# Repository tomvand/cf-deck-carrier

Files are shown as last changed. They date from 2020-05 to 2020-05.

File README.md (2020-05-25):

# Crazyflie 2 deck carrier
[](https://creativecommons.org/licenses/by/4.0/)

Rev 0.1A

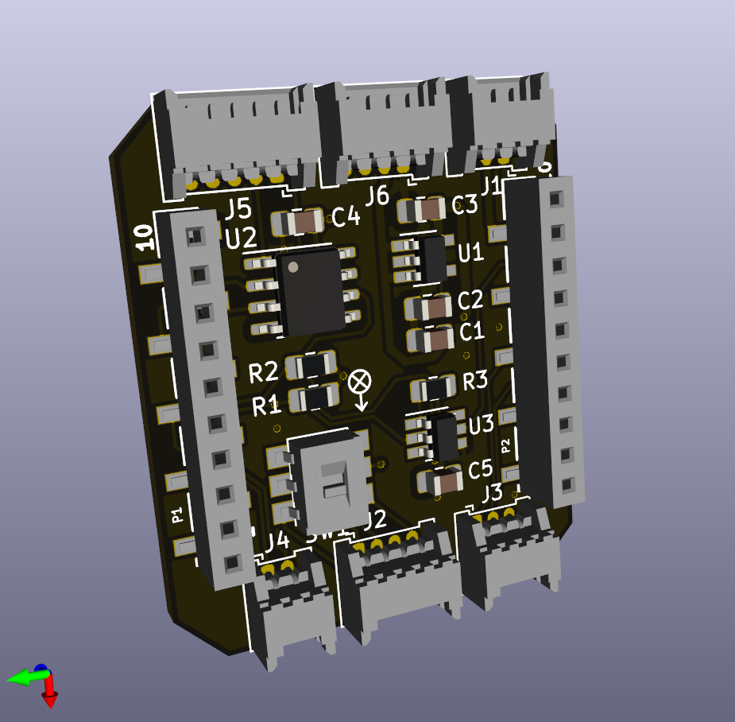
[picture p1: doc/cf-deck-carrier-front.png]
Front


Schematic: [here](cf-deck-carrier.pdf)

Gerbers: [here](gerber/cf-deck-carrier/)

License: [CC BY 4.0](https://creativecommons.org/licenses/by/4.0/). \
Additionally, if you use this design for scientific work, please add a footnote or reference to this webpage: \
Tom van Dijk (2020). *Crazyflie 2 deck carrier*. Micro Air Vehicle Lab (MAVLab), TU Delft. Retrieved from https://github.com/tomvand/cf-deck-carrier

This carrier board lets the Crazyflie 2 decks by [Bitcraze AB ](https://www.bitcraze.io/) be carried by other drones. The board functions similarly to a breakout board but with additional functions. The board is originally designed for the Eachine Trashcan, but may also be useful for other drones.

Nearly all of the features on this carrier board are optional, unused components can be left out to save weight and assembly time. Refer to the *optional features* section below to check which components should be installed for your application.

## Interface
The carrier board should be connected to an autopilot using the connectors `J1` to `J5`. The connectors are grouped by function. In nearly all cases the board can be connected directly to the corresponding autopilot pins.

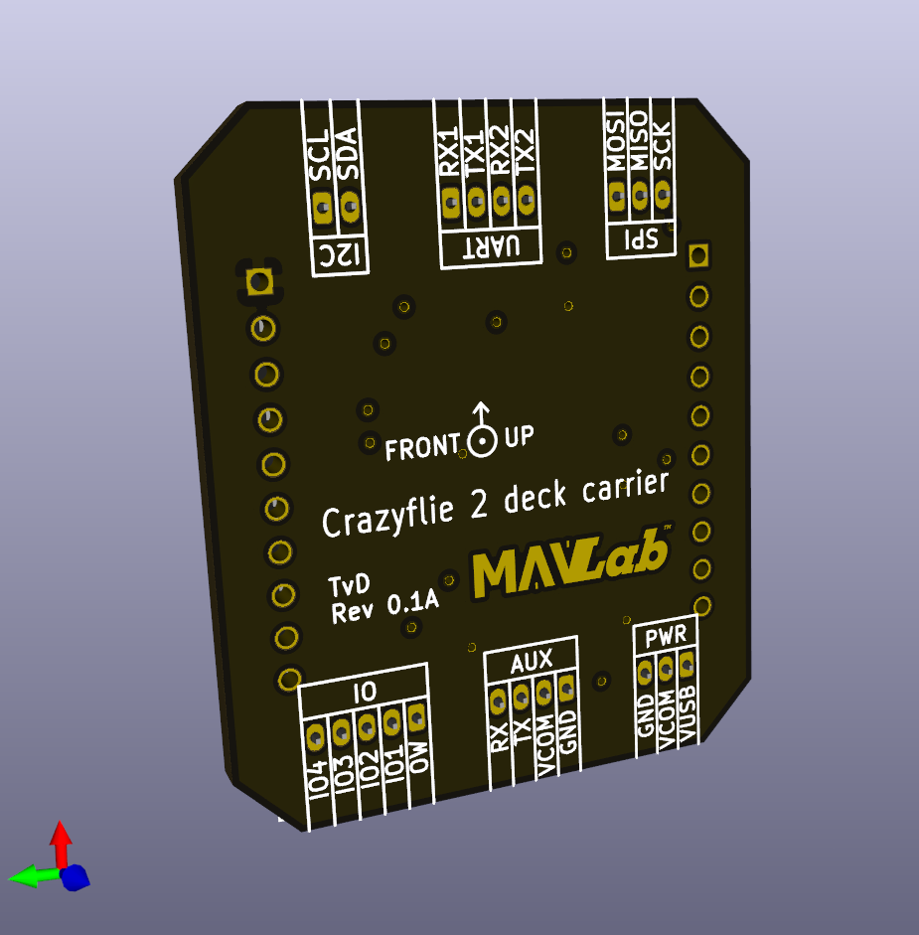
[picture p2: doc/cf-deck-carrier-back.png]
Pinouts


PWR (`J1`):
- VCOM provides power to this board and the decks. VCOM does not need to be regulated.
- VUSB is a power supply *to* the drone, for instance using the Qi charging deck.

UART (`J2`):

SPI (`J3`):
- The IO pins on `J5` are typically used as Chip Select.

I2C (`J4`):

IO (`J5`):
- IO functionality can be replaced by the on-board I2C-to-GPIO and I2C-to-1-Wire bridges for controllers with few free pins.

AUX (`J6`):
- The auxiliary UART is connected directly to either UART1 or UART2.

## Bill of materials
| Ref | Qnty | Value | Cmp name | Footprint | Approx. total cost / 5 |
|---|---|---|---|---|---|
| PCB, | 1 | | | | € 4.57 |
| | | | | |------------------------|
| Subtotal | | | | | € 4.57 |
| | | | | |------------------------|
| C1, | 1 | 1uF | C | 0805 | € 0.20 |
| C2, | 1 | 10nF | C | 0805 | € 0.20 |
| C3, | 1 | 4.7uF | C | 0805 | € 0.20 |
| C4, C5, | 2 | 0.1uF | C | 0805 | € 0.40 |
| R1, R2, R3,  | 3 | 2.2k | R | 0805 | € 1.20 |
| | | | | |------------------------|
| Subtotal | | | | | € 2.20 |
| | | | | |------------------------|
| U1, | 1 | LP2985-3.0 | LP2985-3.0 | SOT-23-5  | € 3.70 |
| U2, | 1 | PCA9536D | PCA9536D | SOIC-8 | € 7.15 |
| U3, | 1 | DS2484 | DS2484 | SOT-23-6  | € 3.35 |
| | | | | |------------------------|
| Subtotal | | | | | € 14.20 |
| | | | | |------------------------|
| J1, | 1 | PWR | Molex PicoBlade 1x3 Horizontal Through-hole 53048-0310 | | € 1.55 |
| J2, | 1 | UART | Molex PicoBlade 1x4 Horizontal Through-hole 53048-0410 | | € 1.85 |
| J3, | 1 | SPI | Molex PicoBlade 1x3 Horizontal Through-hole 53048-0310 | | € 1.55 |
| J4, | 1 | I2C | Molex PicoBlade 1x2 Horizontal Through-hole 53048-0210 | | € 1.25 |
| J5, | 1 | IO | Molex PicoBlade 1x5 Horizontal Through-hole 53048-0510 | | € 1.90 |
| J6, | 1 | UART_AUX | Molex PicoBlade 1x4 Horizontal Through-hole 53048-0410 | | € 1.85 |
| P1, | 1 | CF_EXP_LEFT  | BF090-10-X-B2 | | € 6.60 |
| P2, | 1 | CF_EXP_RIGHT | BF090-10-X-B2 | | € 6.60 |
| SW1, | 1 | CAS-220 | CAS-220B1 | | € 9.20 |
| | | | | |------------------------|
| Subtotal | | | | | € 32.35 |
| | | | | |------------------------|
| Total | | | | | € 53.32 / 5 |

## Ordering information
### PCB
- PCB size: 33x28mm
- PCB layers: 4
- Silkscreen: both sides
- Min. Trace/Space: 6 mil
- Min. Drill: 15 mil

Find the gerber files [here](gerber/cf-deck-carrier/).

PCB manufactoring cost: ~€4.57 / 5 (excl. shipping cost, at [JLCPCB](https://jlcpcb.com/), estimated by [pcbshopper](https://pcbshopper.com/) on Wednesday May 20th 2020)

### PCB with partial assembly
SMT assembly files for JLCPCB: [here](gerber/cf-deck-carrier/jlcpcb/).

#### PCB manufacturing + (partial) assembly and component cost (basic parts: all `C`, `R`)
| | Cost / 5 |
|---|---|
| Assembly incl. component cost | € 15.19  |
| Remaining components | € 46.55  |
| |----------|
| Total | € 61.74  |

#### PCB manufacturing + (partial) assembly and component cost (basic + extended parts: all `C`, `R`, `U`)
| | Cost / 5 |
|---|---|
| Assembly incl. component cost | € 29.87  |
| Remaining components | € 32.35  |
| |----------|
| Total | € 62.22  |

(excl. shipping cost, assembly at [JLCPCB](https://jlcpcb.com/); Wednesday May 20th 2020)

## Assembly
Recommended soldering order:
1. Passives (C, R)
1. ICs (U)
1. Switch (SW)
1. Headers (P)
1. Connectors (J)

## Optional features
### Molex Picoblade connectors
Components: `J1` to `J6`

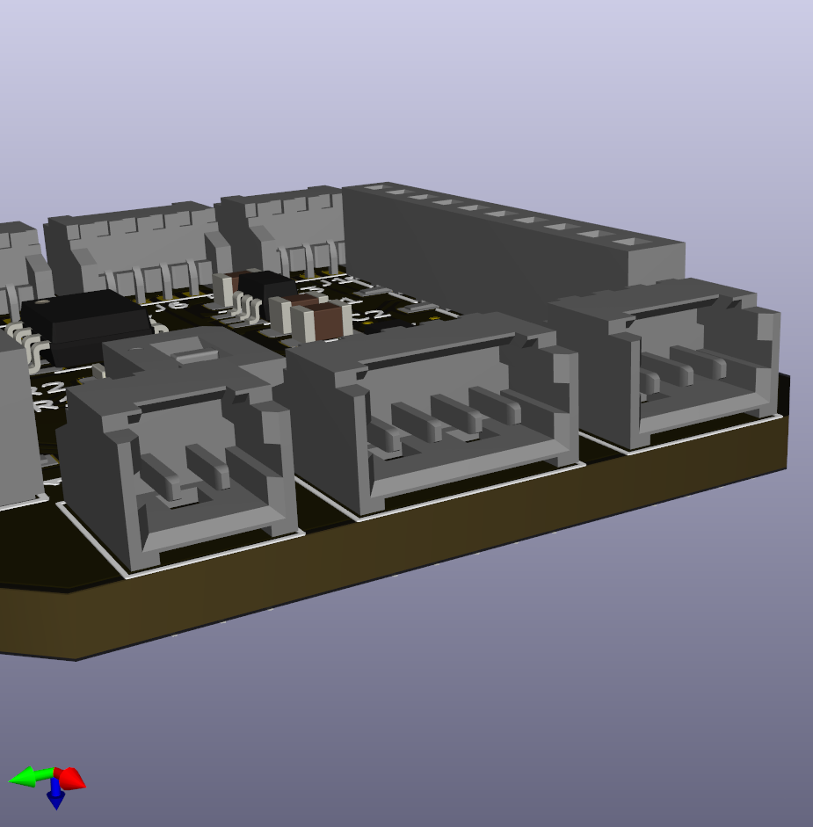
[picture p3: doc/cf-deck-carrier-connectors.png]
Connectors


The PCB is designed for through-hole Molex Picoblade connectors. Unused connectors can be left out to save weight. Wires can also be soldered directly to the connector pads for permanent connections.

### Voltage regulator
Components: `U1`, `C1`, `C2`, `C3`

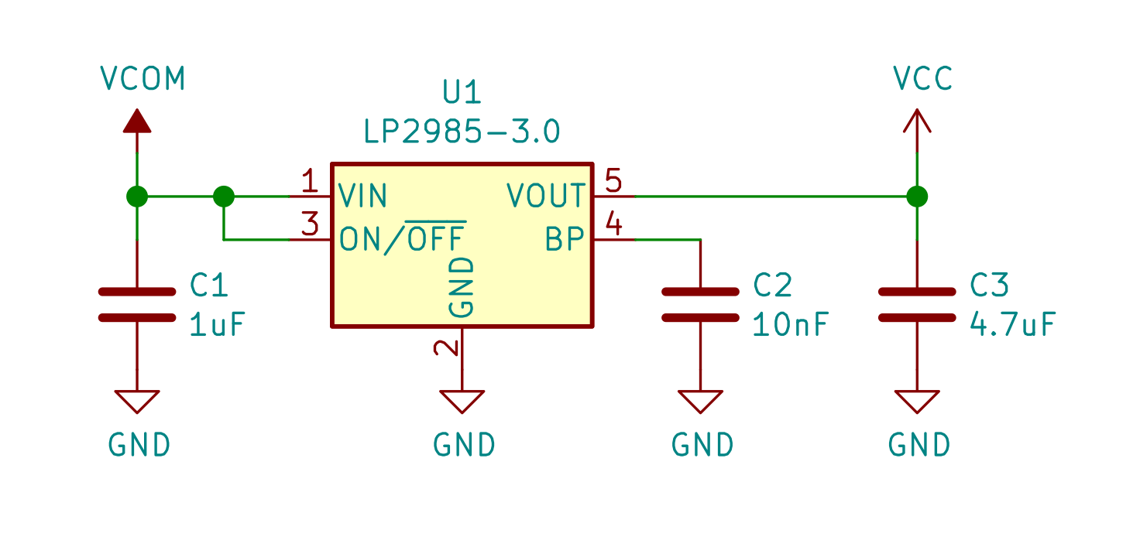
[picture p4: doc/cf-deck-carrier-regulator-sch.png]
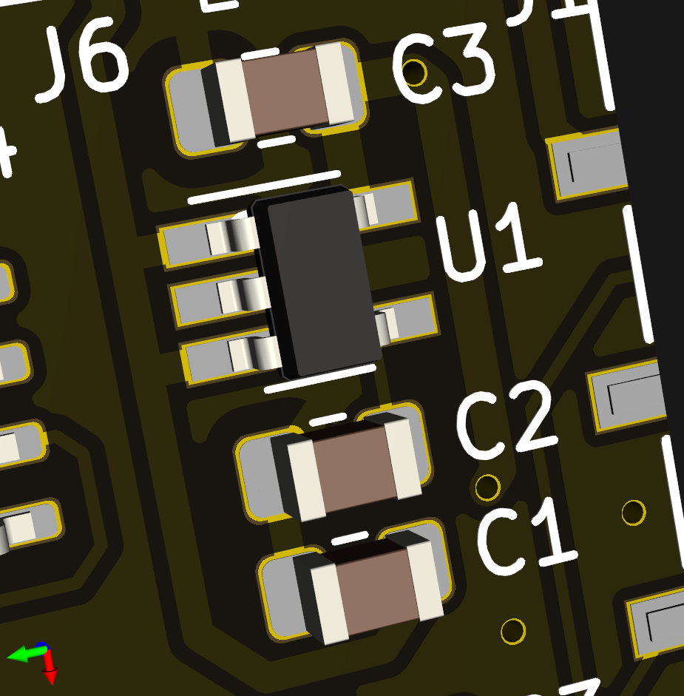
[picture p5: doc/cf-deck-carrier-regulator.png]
Regulator


The carrier board includes a voltage regulator that supplies 3.0V at max 150mA. Input voltage VCOM can be ≤16V, **although compatibility with the crazyflie decks should be checked!**

For autopilots that already supply regulated 3.0V on VCOM, the voltage regulator can be replaced by a solder bridge between VCOM (pad 1) and VCC (pad 5) of `U1` (marked by white line).

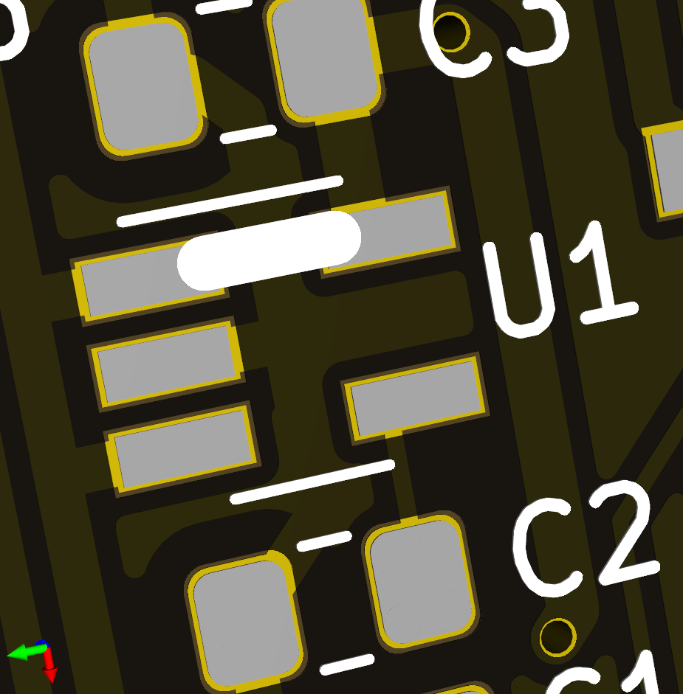
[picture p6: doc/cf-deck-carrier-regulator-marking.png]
Solder bridge marking


### I2C Pull-ups
Components: `R1`, `R2`

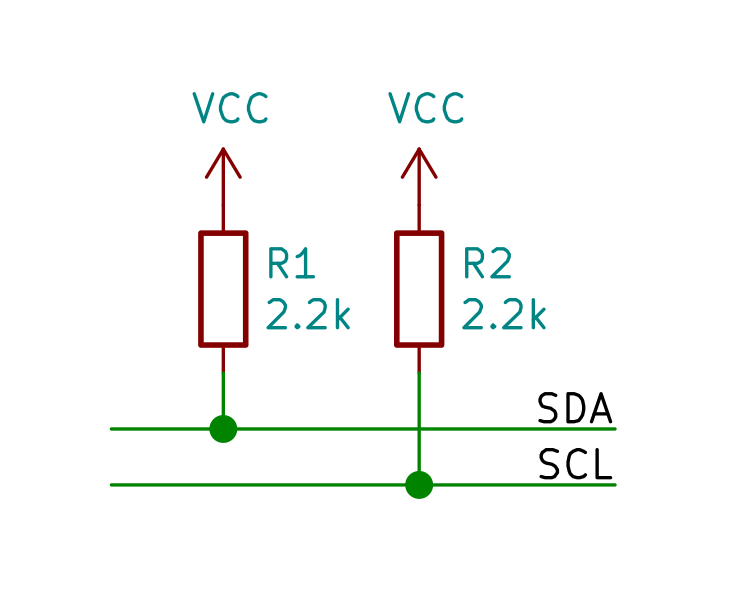
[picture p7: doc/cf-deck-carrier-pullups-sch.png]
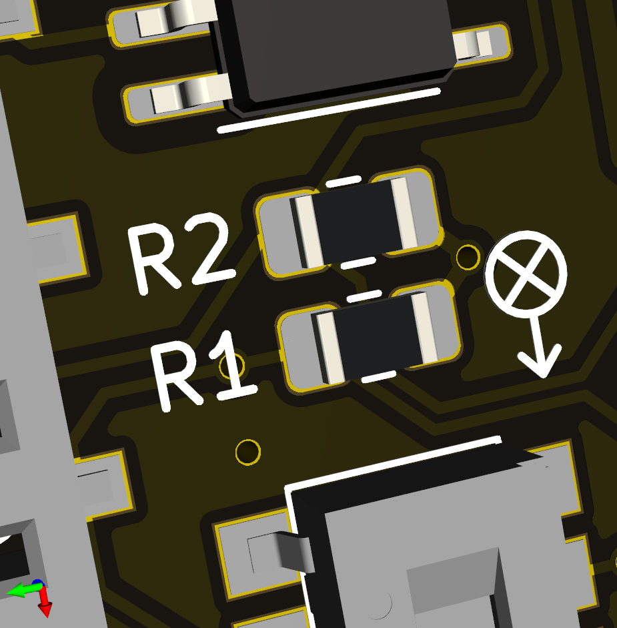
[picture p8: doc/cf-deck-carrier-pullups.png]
Pull-up resistors


The board has space for I2C pull-up resistors (0805) (`R1`, `R2`) if these are not present on the autopilot.

### I2C-to-GPIO
Components: `U2`, `C4`

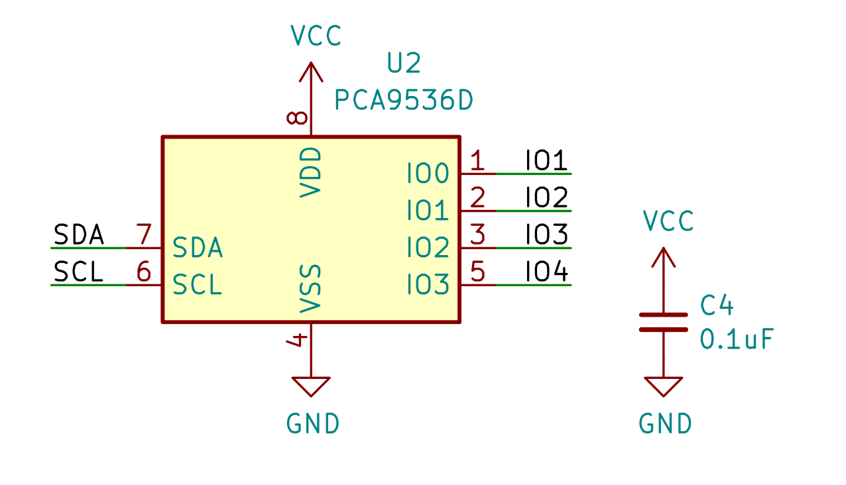
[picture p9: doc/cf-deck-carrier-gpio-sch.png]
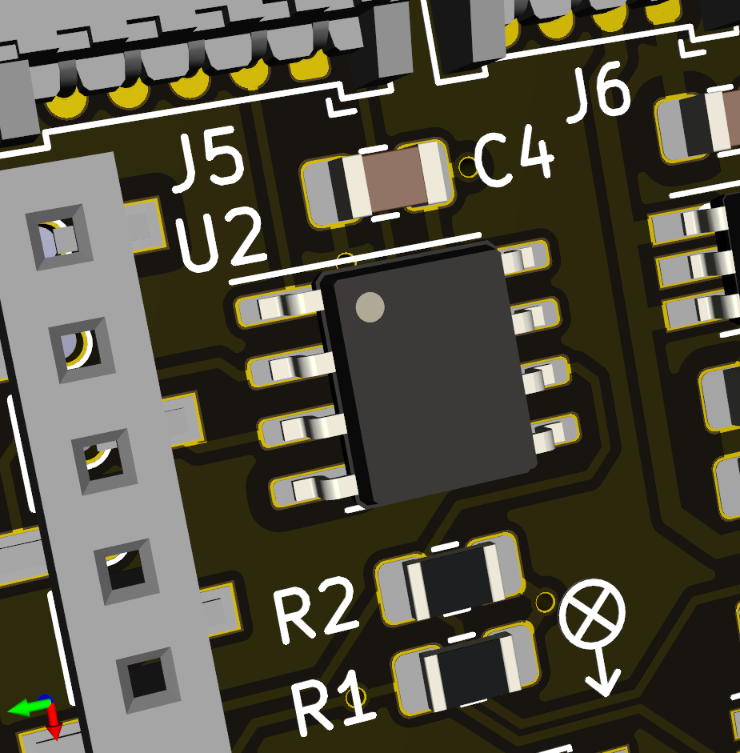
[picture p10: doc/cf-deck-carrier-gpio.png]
I2C-to-GPIO bridge


For drones with a limited number of free pins, the I2C-to-GPIO bridge `U2` can be installed to drive the decks' IO pins. Since most of the IO pins serve as Chip Select for SPI communication, software drivers should take care that the I2C/GPIO operation is completed before SPI communication begins.

The IO inputs on the `IO` connector should not be used if the I2C-to-GPIO bridge is in use.

### I2C-to-1-Wire
Components: `U3`, `R3`, `C5`

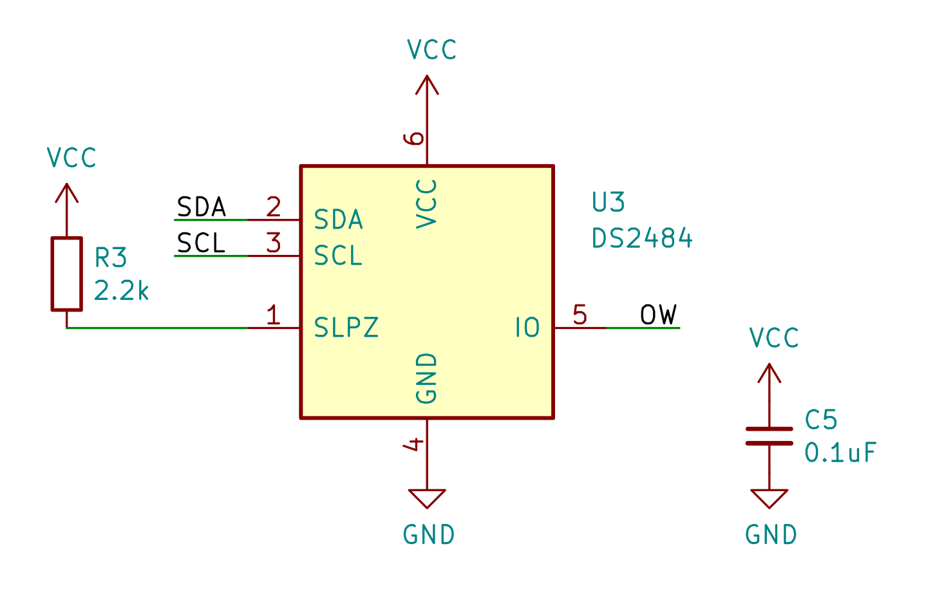
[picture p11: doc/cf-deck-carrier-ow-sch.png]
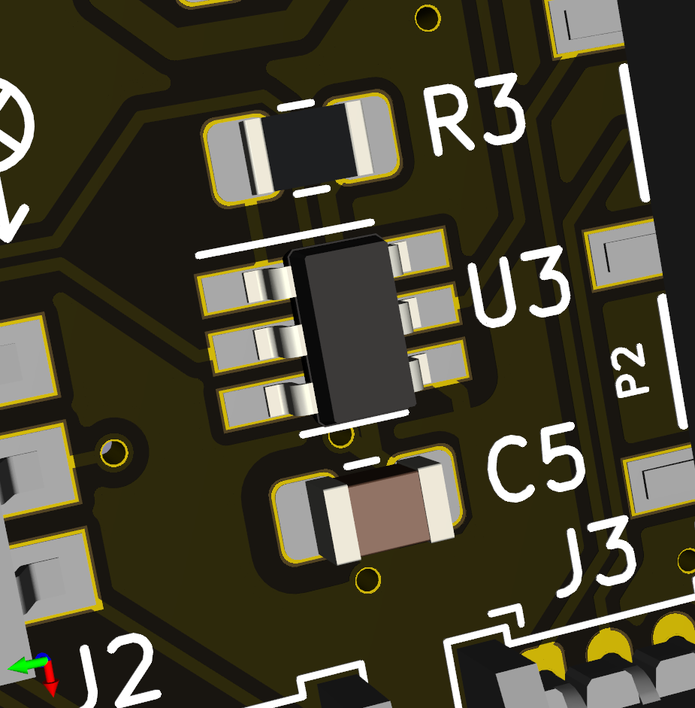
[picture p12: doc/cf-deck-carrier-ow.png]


For drones with a limited number of free pins, the I2C-to-1-Wire bridge `U3` can save another pin by routing 1-Wire data over the existing I2C lines. Note that most decks only use 1-Wire for identification and that not all autopilots support this feature. (Paparazzi, for instance, does not.)

The OW input on the `IO` connector should not be used if the I2C-to-1-Wire bridge is installed.

### Auxiliary connector
Components: `J6`, `SW1`

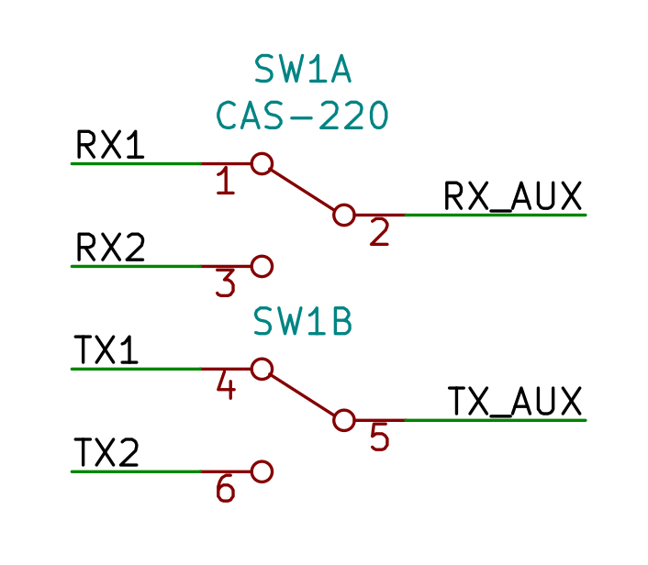
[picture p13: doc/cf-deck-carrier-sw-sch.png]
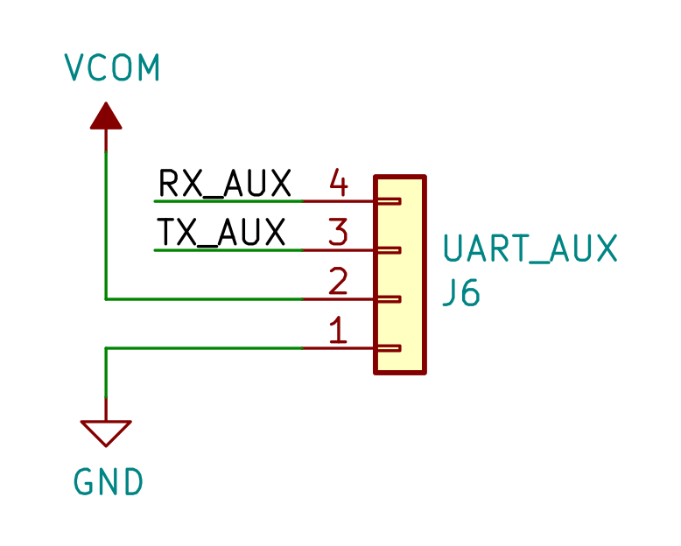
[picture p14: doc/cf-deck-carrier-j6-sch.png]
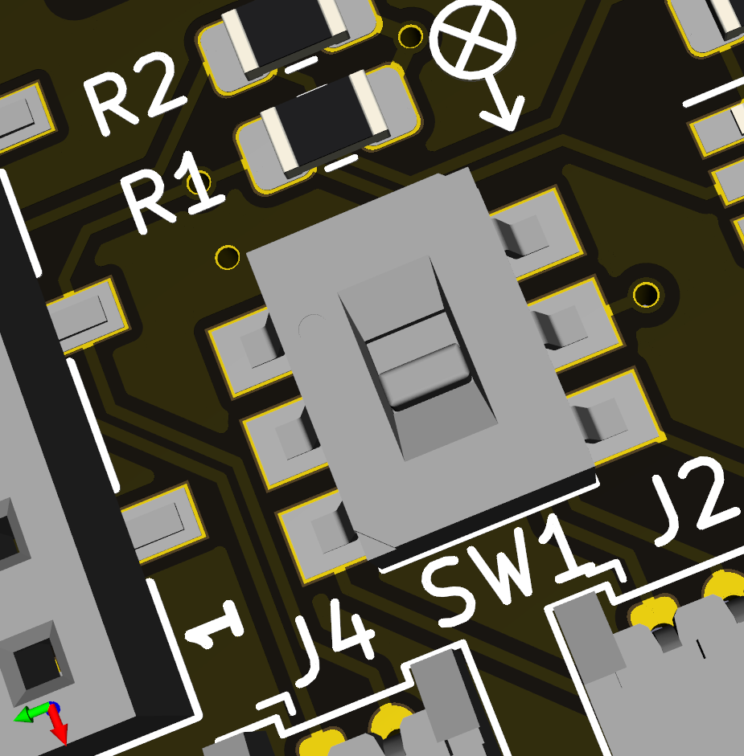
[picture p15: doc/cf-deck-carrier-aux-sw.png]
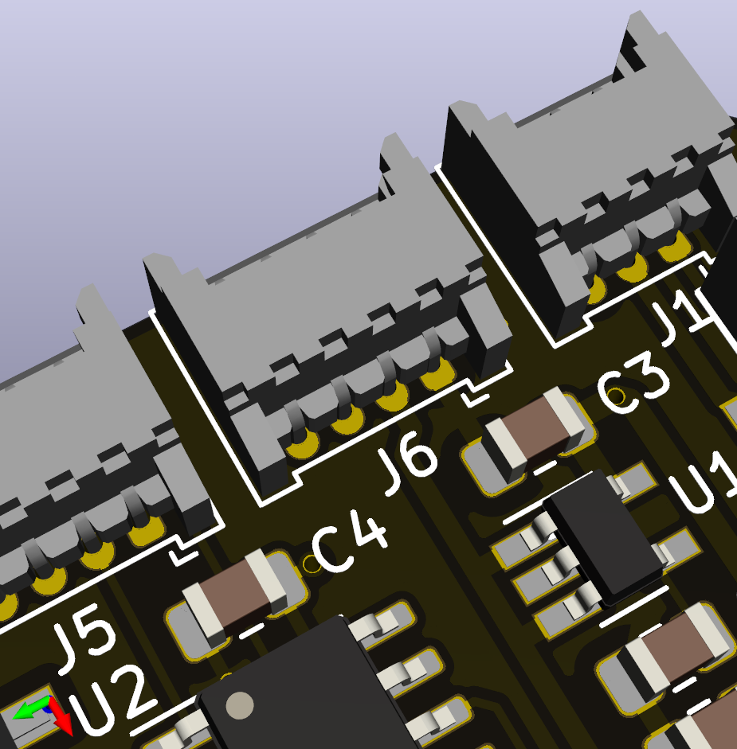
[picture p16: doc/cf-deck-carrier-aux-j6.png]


The AUX connector `J6` can be used to connect another board to the carrier deck. The AUX connector provides unregulated power (VCOM) and a UART bus. Using switch `SW1`, the auxiliary UART can be connected to UART1 or UART2, depending on the decks that are in use.

For permanent installations, switch `SW1` can be replaced by solder bridges between the relevant pads.

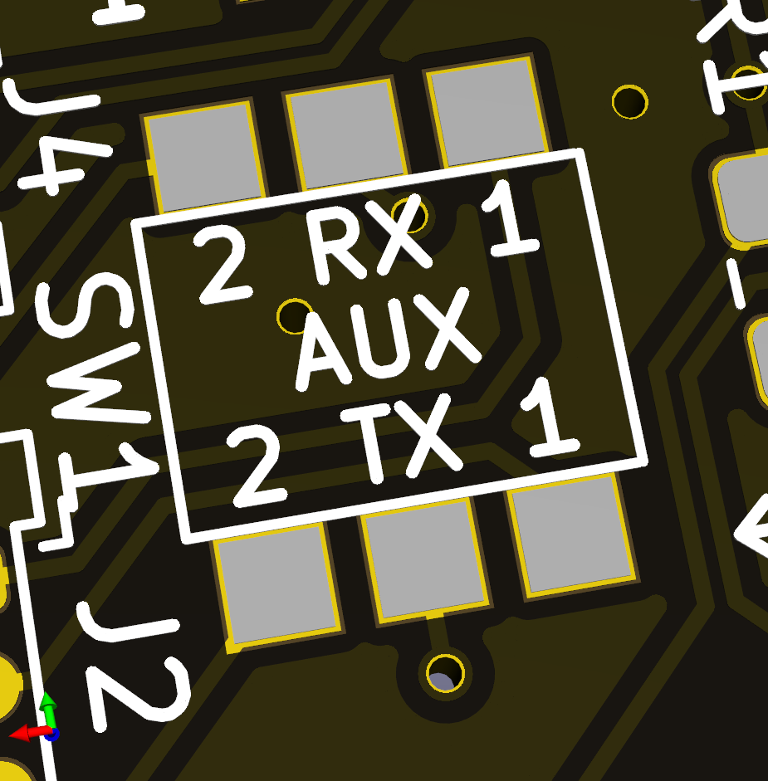
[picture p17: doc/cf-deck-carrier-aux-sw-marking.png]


[cc-by-shield]: https://img.shields.io/badge/License-CC%20BY%204.0-lightgrey.svg

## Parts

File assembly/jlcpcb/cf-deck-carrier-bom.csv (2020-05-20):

Comment | Designator | Footprint | LCSC Part Number | JLCPCB_Lib
1uF | C1 | 0805 | C28323 | Basic
10nF | C2 | 0805 | C1710 | Basic
4.7uF | C3 | 0805 | C1779 | Basic
0.1uF | C4,C5 | 0805 | C49678 | Basic
2.2k | R1,R2,R3 | 0805 | C17520 | Basic
LP2985-3.0 | U1 | SOT-23 | C50088 | Extended
PCA9536D | U2 | SOIC-8 | C129522 | Extended
DS2484 | U3 | SOIC-8 | C124886 | Extended

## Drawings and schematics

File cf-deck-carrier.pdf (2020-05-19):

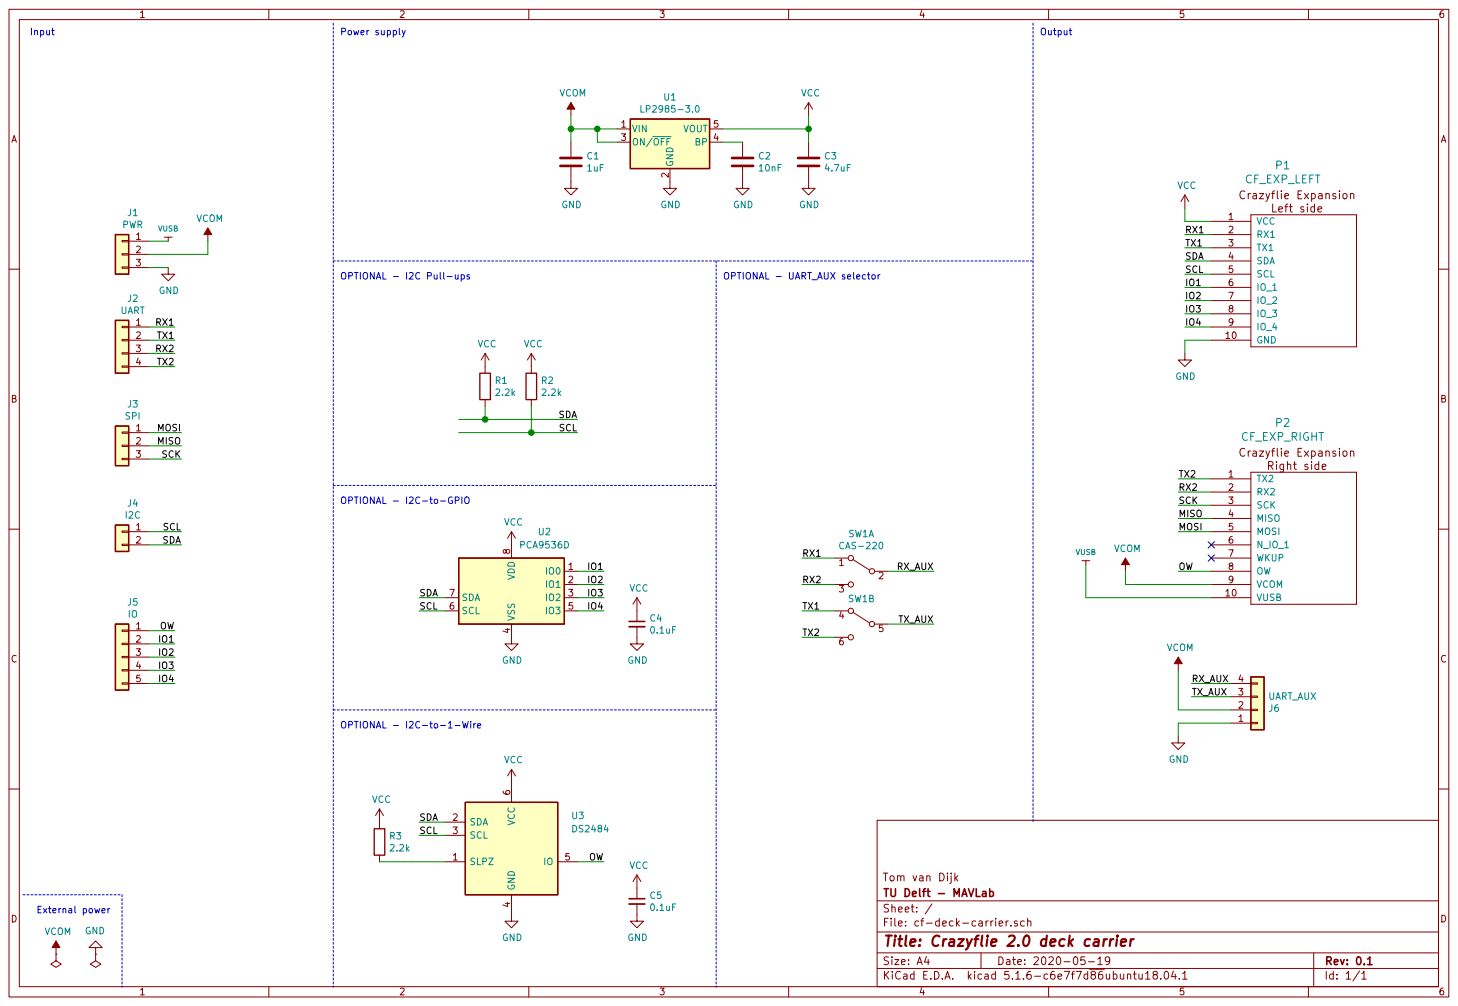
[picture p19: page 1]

2 ON/OFF 3 BP 4 VOUT 5 U1

Id: 1/1 Title: Crazyflie 2.0 deck carrier File: cf-deck-carrier.sch Sheet: / TU Delft - MAVLab

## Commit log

2020-05-15 Add CF symbol library
    [cf-deck-carrier.kicad_pcb, cf-deck-carrier.sch]
2020-05-15 Add CF pcb template
    [cf-deck-carrier.kicad_pcb]
2020-05-15 First draft
    [cf-deck-carrier.sch]
2020-05-15 Add caps and fix uart_aux pin order
    [cf-deck-carrier.sch]
2020-05-15 Add ref numbers, fix ERC
    [cf-deck-carrier.sch]
2020-05-15 Kicad changed things after exporting netlist
2020-05-18 Minor changes by kicad
    [cf-deck-carrier.sch]
2020-05-18 Move headers to bottom of pcb
    [cf-deck-carrier.kicad_pcb]
2020-05-18 Assign available footprints
    [cf-deck-carrier.sch]
2020-05-18 Add CAS-220B footprint
    [cf-deck-carrier.sch]
2020-05-18 Import net and footprints
    [cf-deck-carrier.kicad_pcb, cf-deck-carrier.sch]
2020-05-18 Change U2 to larger package for hand-soldering
    [cf-deck-carrier.sch]
2020-05-18 Group components
    [cf-deck-carrier.kicad_pcb]
2020-05-18 Switch to 4-layer design
    [cf-deck-carrier.kicad_pcb]
2020-05-18 Rough component placement
    [cf-deck-carrier.kicad_pcb]
2020-05-18 Add molex 3D models
    [cf-deck-carrier.kicad_pcb]
2020-05-18 Add CAS-220B 3D model
    [cf-deck-carrier.kicad_pcb]
2020-05-18 Draft component placement
    [cf-deck-carrier.kicad_pcb]
2020-05-18 Set up pcb rules for jlpcb
    [cf-deck-carrier.kicad_pcb]
2020-05-19 Change board outline
    [cf-deck-carrier.kicad_pcb]
2020-05-19 Add power planes
    [cf-deck-carrier.kicad_pcb]
2020-05-19 Initial routing
    [cf-deck-carrier.kicad_pcb, cf-deck-carrier.sch]
2020-05-19 Increase power trace width, enough space anyway
    [cf-deck-carrier.kicad_pcb]
2020-05-19 Clean up silkscreen
    [cf-deck-carrier.kicad_pcb]
2020-05-19 Add connector labels
    [cf-deck-carrier.kicad_pcb]
2020-05-19 Add title to board
    [cf-deck-carrier.kicad_pcb]
2020-05-19 Add credits to pcb
    [cf-deck-carrier.kicad_pcb]
2020-05-19 Add credits to schematic
    [cf-deck-carrier.sch]
2020-05-19 Clean up schematic
    [cf-deck-carrier.kicad_pcb, cf-deck-carrier.sch]
2020-05-19 Export schematic pdf
2020-05-19 Export gerbers
    [cf-deck-carrier-B_Cu.gbr, cf-deck-carrier-B_Mask.gbr, cf-deck-carrier-B_SilkS.gbr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]
2020-05-19 Add solder bridge hints, expand switch pads for easier bridging
    Updated gerbers.
    [cf-deck-carrier-B_Cu.gbr, cf-deck-carrier-B_Mask.gbr, cf-deck-carrier-B_SilkS.gbr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]
2020-05-20 Add link to schematic
2020-05-20 First steps at BOM
    [bom-clean.ods]
2020-05-20 Add BOM to readme
2020-05-20 Add gerber link
2020-05-20 Add PCB ordering information
2020-05-20 Update pcb ordering information
2020-05-20 Add SMT assembly data and files for JLCPCB
    [cf-deck-carrier.sch]
2020-05-20 Do not ignore assembly csv's
    [cf-deck-carrier-bom.csv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]
2020-05-20 Add approximate cost to BOM
    [bom-clean.ods]
2020-05-20 Clean up approx cost
    [bom-clean.ods]
2020-05-20 Add PCB to BOM
    [bom-clean.ods]
2020-05-25 FIX DS2484 footprint
    TODO: update BOM and documentation
    [cf-deck-carrier.kicad_pcb, cf-deck-carrier.sch]
2020-05-25 Minor routing tweaks
    [cf-deck-carrier.kicad_pcb]
2020-05-25 Refilled zones
    [cf-deck-carrier.kicad_pcb]
2020-05-25 Isolate MAVLab logo
    Was VCC first...
    Not entirely sure if this is still a good idea, or that the logo
    should be moved to the silkscreen instead. It is now breaking up
    the VCC power plane. Added a thick trace above it to fix...
    [cf-deck-carrier.kicad_pcb]
2020-05-25 Replace LP2985 footprint for hand-soldering
    [cf-deck-carrier.kicad_pcb, cf-deck-carrier.sch]
2020-05-25 Minor fixes (UART1 routing, silkscreen cleanup)
    [cf-deck-carrier.kicad_pcb]
2020-05-25 Fill empty space with GND
    Note: not connected to pads, want to keep current ground routing
    intact without adding extra loops.
    [cf-deck-carrier.kicad_pcb]
2020-05-25 Re-export gerbers and smt assembly files
    [bom-clean.ods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]
2020-05-27 Move via away from UART lines
    [cf-deck-carrier-B_Cu.gbr, cf-deck-carrier-B_Mask.gbr, cf-deck-carrier-B_SilkS.gbr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]

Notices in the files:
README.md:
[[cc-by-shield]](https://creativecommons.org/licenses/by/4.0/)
